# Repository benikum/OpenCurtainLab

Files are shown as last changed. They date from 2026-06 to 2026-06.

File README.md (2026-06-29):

# OpenCurtainLab

**OpenCurtainLab is an open-source shutter tester for analog camera shutters.**

It combines an ESP32, five optical sensor channels, a flash-sync input, an OLED display, and a standalone browser WebUI. The firmware records raw shutter timing locally. The WebUI analyzes that data into exposure time, exposure deviation, shutter spread, curtain travel behavior, flash-sync timing, charts, project history, backups, CSV exports, and standalone camera reports.

OpenCurtainLab is intended for camera repair, calibration work, repeatable shutter testing, and local documentation of analog camera bodies. It does not require a cloud service or proprietary backend.

<p align="center">
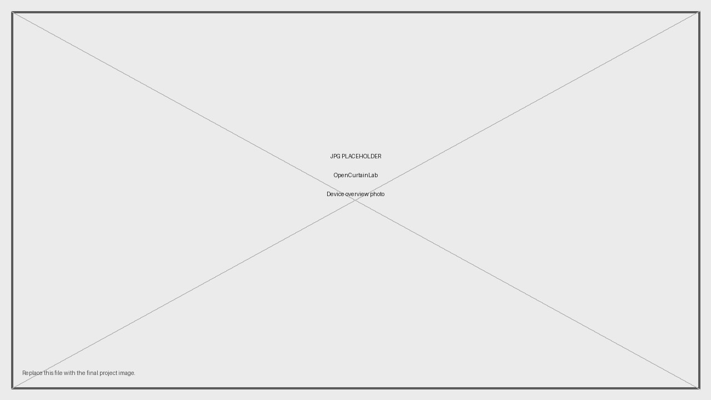
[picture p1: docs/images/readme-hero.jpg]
OpenCurtainLab device
  
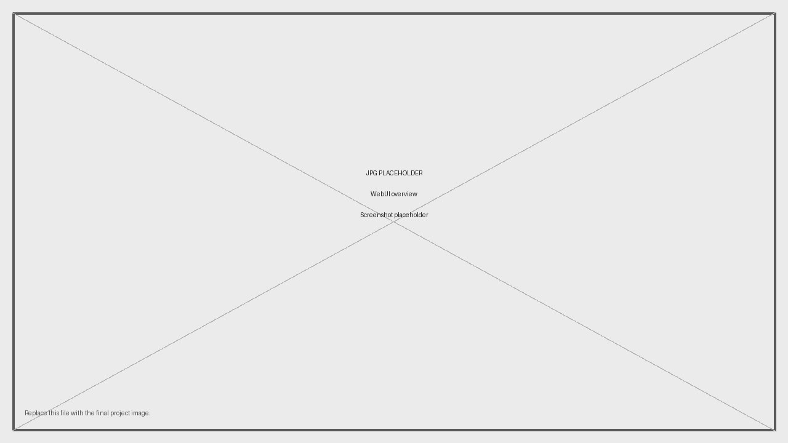
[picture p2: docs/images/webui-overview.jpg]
OpenCurtainLab WebUI
  
</p>

## Features

### Measurement hardware

- Five optical sensor channels for focal-plane shutter timing.
- Measurement modes for horizontal-travel, vertical-travel, and central/leaf shutters.
- Flash-sync input for X-sync timing checks.
- OLED display for setup state, network state, target speed, measurement state, and quick result review.
- Three active-low local buttons for operation without a computer.
- Optional battery-voltage monitoring through a resistor divider.

### Standalone WebUI

- Runs as a normal local HTML file after being downloaded from the device.
- Connects to the ESP32 over the local network.
- Shows measured exposure time, deviation from target speed, shutter spread, and measurement hints.
- Provides timeline, curtain-speed, exposure, and flash-sync visualizations.
- Stores projects and measurement history in browser storage.
- Supports workspace backup import/export, calculated CSV export, and standalone HTML camera reports.

### Local HTTP API

- Local endpoints for status, configuration, diagnostics, WiFi setup, and raw measurement data.
- JSON responses for scripts, tools, or alternative UIs.
- Live sensor diagnostics for wiring, optical alignment, and threshold troubleshooting.

## Repository layout

```text
OpenCurtainLab.ino          Main Arduino sketch and application loop
src/                        Firmware modules, configuration, measurement logic, API, WiFi, OLED
web/                        WebUI source files
web/compiled/               Generated standalone WebUI release file
tools/                      Release and development helper scripts
docs/BUILD_GUIDE.md         Hardware, firmware, and upload guide
docs/API.md                 Firmware HTTP API reference
LICENSE                     Project license
```

## Build the device

The complete hardware and firmware build process is documented here:

**[Open the build guide](docs/BUILD_GUIDE.md)**

The guide covers:

- parts and tools
- ESP32 pinout
- sensor, button, OLED, flash-sync, and battery wiring
- sensor geometry from the current firmware configuration
- Arduino IDE and Arduino CLI setup
- required library versions
- first electrical checks and troubleshooting

<p align="center">
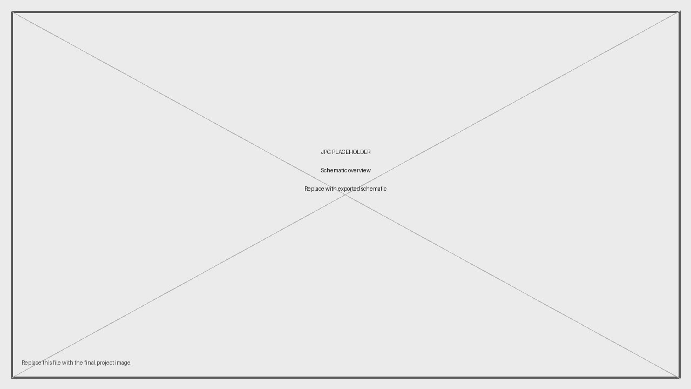
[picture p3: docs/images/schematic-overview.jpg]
OpenCurtainLab electronics overview
  
</p>

## Basic use

### 1. Flash and power the device

Upload the firmware, connect the electronics, and power the ESP32. The OLED shows the current device state.

### 2. Configure WiFi

On first start, the device opens a setup access point named `OpenCurtainLab`. Connect to that access point, open the captive portal, select your WiFi network, enter the password, and save the settings.

### 3. Download the WebUI

After the device is connected to your network, open:

```text
http://opencurtainlab.local
```

The device downloads the compatible compiled WebUI release through the manifest proxy and serves it as `opencurtainlab.html`. Save or open that file in a browser and connect it to the device address shown on the OLED.

### 4. Make a measurement

Place the five-sensor assembly at the camera film gate, point a stable light source through the shutter, select the measurement mode and target speed, and fire the shutter. The firmware records raw timestamps and the WebUI performs the exposure and curtain analysis.

## Local button controls

The three buttons are active-low and wired to GND.

| State | Button | Action |
|---|---|---|
| Ready | Up | Select the next faster target speed. |
| Ready | Down | Select the next slower target speed. |
| Ready | Hold Up | Cycle measurement mode: horizontal, vertical, central. |
| Ready | Select | Open the OLED settings menu. |
| Menu | Up / Down | Move through menu entries. |
| Menu | Select | Change the selected value. |
| Menu | Hold Select | Save menu settings and return to ready mode. |
| Results | Up / Down | Switch result pages or leave the result view. |
| Results | Select | Close result view and return to ready mode. |

The OLED menu gives quick access to sensor sensitivity, target time series, result display behavior, OLED sleep timeout, and network reset.

<p align="center">
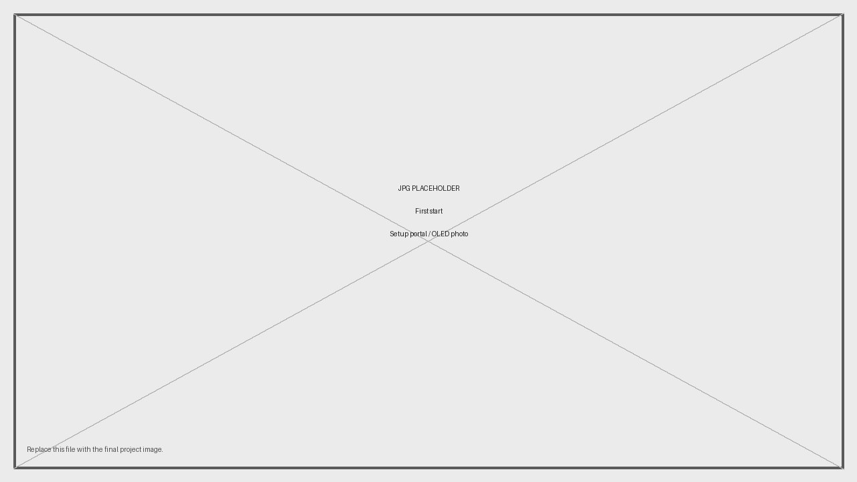
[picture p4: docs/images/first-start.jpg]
OpenCurtainLab first start
  
</p>

## API documentation

The firmware exposes a local HTTP API for status, runtime configuration, WiFi setup, live sensor diagnostics, and measurement data.

**[Open the API documentation](docs/API.md)**

Typical endpoints:

```text
GET  /version
GET  /status
GET  /config
POST /config
GET  /data
GET  /sensors
GET  /wifi/status
GET  /wifi/scan
POST /wifi
```

## AI usage transparency

AI tools were used during development as an assistant for code review, refactoring, documentation drafting, and implementation exploration. The project design, hardware decisions, test results, firmware behavior, API behavior, and published releases remain the responsibility of the maintainer.

## License

OpenCurtainLab is released under the MIT License. See [LICENSE](LICENSE).

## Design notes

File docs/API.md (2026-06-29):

# OpenCurtainLab Firmware API

This document describes the current OpenCurtainLab firmware HTTP API for firmware `0.1.2`. All endpoints are served by the ESP32 on the local network.

The API exposes raw device state and raw measurement data. Exposure analysis, charting, reports, and measurement hints are calculated in the WebUI.

## Security model

OpenCurtainLab is designed for trusted local networks only. The firmware API does not provide user accounts, API tokens, HTTPS, request signing, or per-user permissions.

Do not expose the device to the public internet, do not port-forward it from a router, and do not place it on an untrusted guest network. Anyone who can reach the device on the network can read status data, change runtime settings, access live sensor diagnostics, and use setup endpoints when available.

Recommended use:

- Use a private LAN you control.
- Keep the device behind your router or firewall.
- Avoid public, shared, or guest WiFi networks.
- Power down or disconnect the device when it is not needed in an untrusted environment.

## Base URLs

Station mode:

```text
http://opencurtainlab.local
```

or the station IP address shown on the OLED.

Setup access-point mode:

```text
http://192.168.4.1
```

API responses are JSON unless the endpoint description says otherwise. CORS preflight is supported for the documented API paths.

## Endpoint summary

| Method | Endpoint | Response type | Purpose |
|---|---|---|---|
| `GET` | `/` | HTML | Setup portal in AP mode; WebUI download proxy in station mode. |
| `GET` | `/status` | JSON | Device, network, uptime, measurement counter, battery, and error status. |
| `GET` | `/config` | JSON | Firmware capabilities and current runtime settings. |
| `POST` | `/config` | JSON | Partial runtime settings update. |
| `GET` | `/data` | JSON | Latest raw measurement packet. |
| `GET` | `/sensors` | JSON | Live sensor and flash diagnostics. |
| `GET` | `/version` | JSON | Manifest availability, current firmware, newest project version, and compatible WebUI bugfix version. |
| `GET` | `/wifi/status` | JSON | WiFi provisioning state for the setup portal. |
| `GET` | `/wifi/scan` | JSON | Nearby WiFi networks for the setup portal. |
| `POST` | `/wifi` | JSON | Test and store WiFi credentials while AP mode is active. |

## Current firmware constants exposed by the API

These values come from `src/Config.h` in this release.

| Field | Value |
|---|---:|
| `version` | `0.1.2` |
| `sensorCount` | `5` |
| `sensorDistanceXmm` | `7.62` |
| `sensorDistanceYmm` | `5.08` |
| `maxTargetTime` | `2000` |
| `displayRotation` | `0` |
| `batteryEmptyVoltage` | `7.0` |
| `batteryFullVoltage` | `9.3` |

## Error response format

Most error responses use this compact format:

```json
{
  "ok": false,
  "error": "invalid_json"
}
```

Known error strings:

| Error | Meaning |
|---|---|
| `missing_body` | A `POST` request did not contain a body. |
| `invalid_json` | The submitted JSON could not be parsed. |
| `sensors unavailable` | The sensor manager is not attached. |
| `ssid missing` | WiFi setup request did not include an SSID. |
| `wifi_setup_locked_in_station_mode` | `/wifi` was called while the device was not in setup AP mode. |
| `not found` | Unknown route in station mode. |

## `GET /`

In setup AP mode, root serves the embedded WiFi setup portal.

In station mode, root fetches `web/manifest.json`, selects the newest compatible compiled WebUI entry, downloads the compiled HTML, and returns it to the browser as an attachment:

```http
Content-Disposition: attachment; filename="opencurtainlab.html"
Content-Type: text/html; charset=utf-8
```

The full WebUI is not embedded in firmware. The embedded firmware only contains the setup portal.

## `GET /status`

Returns runtime status.

```bash
curl http://opencurtainlab.local/status
```

Example response:

```json
{
  "device": "OpenCurtainLab",
  "version": "0.1.2",
  "uptime": 1234,
  "measCount": 7,
  "batteryVoltage": 8.62,
  "batteryLow": false,
  "deviceStatus": {
    "error": "none",
    "errorText": "",
    "subsystem": "none"
  },
  "network": {
    "connected": true,
    "apMode": false,
    "ip": "192.168.178.42",
    "apIp": "0.0.0.0",
    "hostname": "opencurtainlab",
    "mdns": "opencurtainlab.local",
    "mdnsStarted": true,
    "rssi": -54,
    "savedSsid": "WorkshopWiFi",
    "currentSsid": "WorkshopWiFi",
    "hint": "none",
    "hintText": ""
  }
}
```

Top-level fields:

| Field | Type | Description |
|---|---|---|
| `device` | string | Device name. |
| `version` | string | Firmware version. |
| `uptime` | integer | Seconds since boot. |
| `measCount` | integer | Number of measurement results produced since boot. |
| `batteryVoltage` | number | Calculated battery voltage, or `0` when battery monitoring is disabled. |
| `batteryLow` | boolean | `true` when battery monitoring is enabled and voltage is at or below `BATTERY_EMPTY_VOLTAGE`. |
| `deviceStatus` | object | Device-level error state. |
| `network` | object | Current WiFi and mDNS state. |

Device error keys:

| Key | Meaning |
|---|---|
| `none` | No device error. |
| `network_access_point_failed` | Setup access point could not be started. |
| `display_init_failed` | OLED initialization failed. Measurement and API can continue. |

Device subsystem keys:

| Key |
|---|
| `none` |
| `sensor` |
| `network` |
| `storage` |
| `display` |

Network hint keys:

| Key | Meaning |
|---|---|
| `none` | No network hint. |
| `no_credentials` | No saved WiFi credentials. |
| `access_point_active` | Setup AP is active. |
| `connection_failed` | Station connection failed or AP fallback is active. |
| `reconnecting` | Device is trying to reconnect. |
| `mdns_failed` | Station WiFi works, but mDNS failed. |

## `GET /config`

Returns firmware capabilities and sanitized runtime settings.

```bash
curl http://opencurtainlab.local/config
```

Example response:

```json
{
  "device": "OpenCurtainLab",
  "version": "0.1.2",
  "ip": "192.168.178.42",
  "mdnsName": "opencurtainlab",
  "sensorDistanceXmm": 7.62,
  "sensorDistanceYmm": 5.08,
  "displayRotation": 0,
  "sensorCount": 5,
  "maxTargetTime": 2000,
  "batteryVoltageEnabled": true,
  "batteryEmptyVoltage": 7.0,
  "batteryFullVoltage": 9.3,
  "sensorReadModel": "absolute_adc_threshold",
  "sensorThresholds": {
    "lowOnRaw": 1100,
    "lowOffRaw": 1250,
    "mediumOnRaw": 2100,
    "mediumOffRaw": 2250,
    "highOnRaw": 3100,
    "highOffRaw": 3250
  },
  "targetSeriesOptions": ["standard", "custom"],
  "targetTimesStandard": [1, 2, 4, 8, 15, 30, 60, 125, 250, 500, 1000, 2000],
  "targetTimesCustom": [1, 2, 5, 10, 25, 50, 100, 250, 500, 1000, 2000],
  "modes": ["vertical", "horizontal", "central"],
  "settings": {
    "defaultMeasurementMode": "horizontal",
    "defaultTargetTime": 500,
    "sensorSensitivity": "medium",
    "resultDisplay": "until_button",
    "targetSeries": "standard",
    "customTargetTimes": [1, 2, 5, 10, 25, 50, 100, 250, 500, 1000, 2000],
    "oledSleepMinutes": 5
  },
  "githubProjectUrl": "https://github.com/benikum/OpenCurtainLab",
  "webManifestUrl": "https://raw.githubusercontent.com/benikum/OpenCurtainLab/refs/heads/main/web/manifest.json",
  "webAppDelivery": "manifest_proxy"
}
```

Capability fields:

| Field | Type | Description |
|---|---|---|
| `sensorDistanceXmm` | number | Physical sensor spacing for horizontal-travel analysis. Current value: `7.62`. |
| `sensorDistanceYmm` | number | Physical sensor spacing for vertical-travel analysis. Current value: `5.08`. |
| `displayRotation` | integer | OLED rotation from firmware config. |
| `sensorCount` | integer | Number of sensor channels. |
| `maxTargetTime` | integer | Maximum accepted target denominator. |
| `batteryVoltageEnabled` | boolean | Whether firmware battery monitoring is enabled. |
| `batteryEmptyVoltage` | number | Voltage used as empty/low reference. |
| `batteryFullVoltage` | number | Voltage used as full reference. |
| `sensorReadModel` | string | Current sensor model. `absolute_adc_threshold` means no calibration baseline is used. |
| `sensorThresholds` | object | Raw ADC hysteresis thresholds for sensitivity presets. |
| `targetSeriesOptions` | string array | Supported target speed series. |
| `targetTimesStandard` | integer array | Built-in standard shutter speed denominators. |
| `targetTimesCustom` | integer array | Current custom shutter speed denominators. |
| `modes` | string array | Supported measurement modes. |

Runtime settings object:

| Field | Type | Values |
|---|---|---|
| `defaultMeasurementMode` | string | `vertical`, `horizontal`, `central` |
| `defaultTargetTime` | integer | Exposure denominator, for example `500` for 1/500 s. |
| `sensorSensitivity` | string | `low`, `medium`, `high` |
| `resultDisplay` | string | `until_button`, `2s`, `5s`, `10s`, `none` |
| `targetSeries` | string | `standard`, `custom` |
| `customTargetTimes` | integer array | Positive exposure denominators. |
| `oledSleepMinutes` | integer | `0`, `1`, `5`, `10`, `30` |

## `POST /config`

Applies a partial runtime-settings update. Omitted fields are left unchanged.

```bash
curl -X POST http://opencurtainlab.local/config \
  -H "Content-Type: application/json" \
  -d '{"sensorSensitivity":"high","defaultTargetTime":250}'
```

Accepted public fields:

| Field | Type | Values |
|---|---|---|
| `defaultMeasurementMode` | string | `vertical`, `horizontal`, `central` |
| `defaultTargetTime` | integer | Exposure denominator. Sanitized to the nearest supported target time. |
| `sensorSensitivity` | string | `low`, `medium`, `high` |
| `resultDisplay` | string | `until_button`, `2s`, `5s`, `10s`, `none` |
| `targetSeries` | string | `standard`, `custom` |
| `customTargetTimes` | integer array | Positive denominators, sorted and de-duplicated by firmware. |
| `oledSleepMinutes` | integer | `0`, `1`, `5`, `10`, `30` |

Successful response:

```json
{
  "ok": true,
  "changed": true,
  "settings": {
    "defaultMeasurementMode": "horizontal",
    "defaultTargetTime": 250,
    "sensorSensitivity": "high",
    "resultDisplay": "until_button",
    "targetSeries": "standard",
    "customTargetTimes": [1, 2, 5, 10, 25, 50, 100, 250, 500, 1000, 2000],
    "oledSleepMinutes": 5
  }
}
```

Notes:

- `maxTargetTime` is a build-time capability and is ignored if posted.
- Invalid enum values fall back to firmware defaults during sanitization.
- Custom target times are sorted, de-duplicated, capped by firmware limits, and filtered against `maxTargetTime`.
- If the request body is syntactically valid JSON but contains no effective change, `changed` is `false`.
- Only the fields documented above are part of the public settings schema for this release.

## `GET /data`

Returns the latest raw measurement packet. Exposure analysis is intentionally performed in the WebUI.

```bash
curl http://opencurtainlab.local/data
```

Before the first measurement:

```json
{
  "measCount": 0,
  "mode": "horizontal",
  "target": 500,
  "sensorDistanceXmm": 7.62,
  "sensorDistanceYmm": 5.08,
  "valid": false
}
```

Example valid measurement:

```json
{
  "measCount": 7,
  "mode": "horizontal",
  "target": 500,
  "sensorDistanceXmm": 7.62,
  "sensorDistanceYmm": 5.08,
  "valid": true,
  "id": "m_123456_7",
  "baseUs": 987654321,
  "sensors": [
    { "id": 0, "activated": true, "raw": 420, "openUs": 987654321, "closeUs": 987656400 },
    { "id": 1, "activated": true, "raw": 390, "openUs": 987654450, "closeUs": 987656530 },
    { "id": 2, "activated": true, "raw": 430, "openUs": 987654600, "closeUs": 987656680 },
    { "id": 3, "activated": true, "raw": 410, "openUs": 987654750, "closeUs": 987656830 },
    { "id": 4, "activated": true, "raw": 405, "openUs": 987654900, "closeUs": 987656980 }
  ],
  "flash": {
    "detected": true,
    "raw": 0,
    "triggerUs": 987654100
  }
}
```

Top-level fields:

| Field | Type | Description |
|---|---|---|
| `measCount` | integer | Measurement counter since boot. |
| `mode` | string | Measurement mode used for the packet. |
| `target` | integer | Target shutter denominator. |
| `sensorDistanceXmm` | number | Horizontal spacing used by the WebUI. |
| `sensorDistanceYmm` | number | Vertical spacing used by the WebUI. |
| `valid` | boolean | Whether the packet contains a measurement result. |
| `id` | string | Measurement id. Present only after a result exists. |
| `baseUs` | integer | Base timestamp in microseconds. Present only after a result exists. |
| `sensors` | array | Raw per-sensor result objects. Present only after a result exists. |
| `flash` | object | Flash-sync result. Present only after a result exists. |

Sensor result fields:

| Field | Type | Description |
|---|---|---|
| `id` | integer | Sensor index, starting at `0`. |
| `activated` | boolean | Whether this sensor was covered during the measurement. |
| `raw` | integer | Last raw ADC value for this sensor. |
| `openUs` | integer | Timestamp when the sensor became active. |
| `closeUs` | integer | Timestamp when the sensor became inactive again. |

Flash result fields:

| Field | Type | Description |
|---|---|---|
| `detected` | boolean | Whether the flash contact was triggered. |
| `raw` | integer | Last raw digital input value. |
| `triggerUs` | integer | Trigger timestamp in microseconds. |

Measurement hints such as timeout, incomplete sensor coverage, and too few sensors are derived by the WebUI from the raw timestamps. The firmware does not emit measurement hint keys in `/data`.

## `GET /sensors`

Returns a live, non-mutating diagnostics snapshot. Diagnostic reads do not create measurement edges.

```bash
curl http://opencurtainlab.local/sensors
```

Example response:

```json
{
  "ok": true,
  "timeUs": 123456789,
  "sensorCount": 5,
  "onThresholdRaw": 2100,
  "offThresholdRaw": 2250,
  "sensors": [
    {
      "id": 0,
      "pin": 36,
      "raw": 4095,
      "onThresholdRaw": 2100,
      "offThresholdRaw": 2250,
      "active": false,
      "trackedActive": false,
      "wasActivated": false,
      "openUs": 0,
      "closeUs": 0
    }
  ],
  "flash": {
    "pin": 14,
    "raw": 1,
    "active": false,
    "trackedActive": false,
    "detected": false,
    "triggerUs": 0
  }
}
```

Sensor diagnostics fields:

| Field | Type | Description |
|---|---|---|
| `timeUs` | integer | ESP32 timestamp in microseconds. |
| `sensorCount` | integer | Number of configured sensors. |
| `onThresholdRaw` | integer | Current activation threshold. |
| `offThresholdRaw` | integer | Current release threshold. |
| `sensors[].pin` | integer | ESP32 GPIO for the sensor. |
| `sensors[].raw` | integer | Current raw ADC value. |
| `sensors[].active` | boolean | Current diagnostic active state from the raw value. |
| `sensors[].trackedActive` | boolean | Measurement engine tracked state. |
| `sensors[].wasActivated` | boolean | Whether the sensor was activated during the current/last measurement window. |
| `flash.pin` | integer | ESP32 GPIO for flash sync. |
| `flash.raw` | integer | Current raw digital value. |
| `flash.active` | boolean | Current diagnostic active state. |

In the WebUI developer console, `oclSensors()` prints the diagnostics as a table when developer helpers are enabled.

## `GET /version`

Returns update information from the remote WebUI manifest. The WebUI uses this to show firmware and WebUI updates separately.

```bash
curl http://opencurtainlab.local/version
```

Example response when the manifest is available:

```json
{
  "manifestAvailable": true,
  "currentFirmware": "0.1.2",
  "projectVersion": "0.1.2",
  "bugfixversion": "0.1.2"
}
```

Example response when the manifest cannot be reached or parsed:

```json
{
  "manifestAvailable": false,
  "currentFirmware": "0.1.2",
  "projectVersion": "",
  "bugfixversion": ""
}
```

Fields:

| Field | Type | Description |
|---|---|---|
| `manifestAvailable` | boolean | `true` when `web/manifest.json` was fetched and parsed. |
| `currentFirmware` | string | Firmware version running on the ESP32. |
| `projectVersion` | string | Newest project version from the manifest. Empty when the manifest is unavailable. |
| `bugfixversion` | string | Highest `entries[].version` whose `match` pattern is compatible with `currentFirmware`. Empty when no compatible manifest entry is available. |

## `GET /wifi/status`

Returns WiFi provisioning state for the setup portal.

```bash
curl http://192.168.4.1/wifi/status
```

Example response:

```json
{
  "ok": true,
  "connected": false,
  "apMode": true,
  "ip": "0.0.0.0",
  "apIp": "192.168.4.1",
  "hostname": "opencurtainlab",
  "mdnsStarted": false,
  "hasSaved": false,
  "savedSsid": "",
  "currentSsid": "",
  "hint": "access_point_active",
  "hintText": "Setup access point is active",
  "lastError": ""
}
```

## `GET /wifi/scan`

Returns nearby WiFi networks for the setup portal.

```bash
curl http://192.168.4.1/wifi/scan
```

Example response:

```json
{
  "ok": true,
  "networks": [
    { "ssid": "WorkshopWiFi", "rssi": -51, "secure": true },
    { "ssid": "Guest", "rssi": -78, "secure": false }
  ]
}
```

## `POST /wifi`

Tests and stores WiFi credentials only while setup AP mode is active.

JSON request:

```bash
curl -X POST http://192.168.4.1/wifi \
  -H "Content-Type: application/json" \
  -d '{"ssid":"WorkshopWiFi","password":"secret-password"}'
```

Form-style fields are also accepted by the firmware.

Successful or failed connection test responses use the same shape as `/wifi/status`. On failed connection, `ok` is `false` and `error` is set:

```json
{
  "ok": false,
  "connected": false,
  "apMode": true,
  "ip": "0.0.0.0",
  "apIp": "192.168.4.1",
  "hostname": "opencurtainlab",
  "mdnsStarted": false,
  "hasSaved": false,
  "savedSsid": "",
  "currentSsid": "",
  "hint": "connection_failed",
  "hintText": "WiFi connection failed",
  "lastError": "connection failed",
  "error": "connection failed"
}
```

When called in station mode:

```json
{
  "ok": false,
  "error": "wifi_setup_locked_in_station_mode"
}
```

## WebUI manifest

The WebUI compatibility database is stored in:

```text
web/manifest.json
```

Current manifest shape:

```json
{
  "schema": "opencurtainlab-web-manifest-v1",
  "projectVersion": "0.1.2",
  "entries": [
    {
      "match": "0.1.x",
      "version": "0.1.2",
      "url": "https://raw.githubusercontent.com/benikum/OpenCurtainLab/refs/heads/main/web/compiled/compiled-v0.1.2.html"
    }
  ]
}
```

Selection rules:

- `projectVersion` is the canonical project version used by `tools/release.py`.
- `match` is the firmware compatibility pattern, for example `0.1.x`.
- `version` is the WebUI release selected for compatible firmware.
- The middle version number is treated as the API version.
- If multiple entries match, the firmware selects the highest patch version.

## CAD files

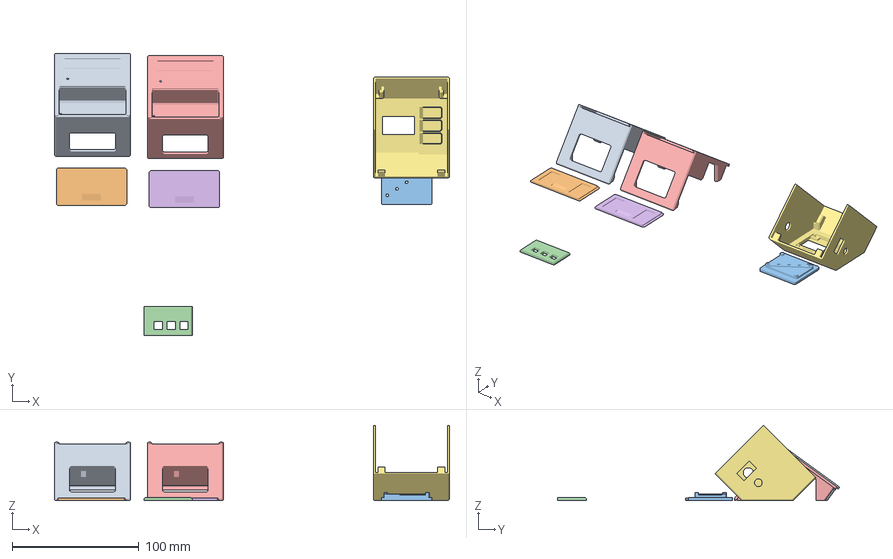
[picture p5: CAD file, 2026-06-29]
3d/OpenCurtainLab - Bambu A1 mini.3mf
311.6 x 222.8 x 59.5 mm
OpenCurtainLab - Case Base.stl x 2
OpenCurtainLab - Battery Door.stl x 2
OpenCurtainLab - Mask.stl
OpenCurtainLab - Button Frame.stl
OpenCurtainLab - Case Outer.stl

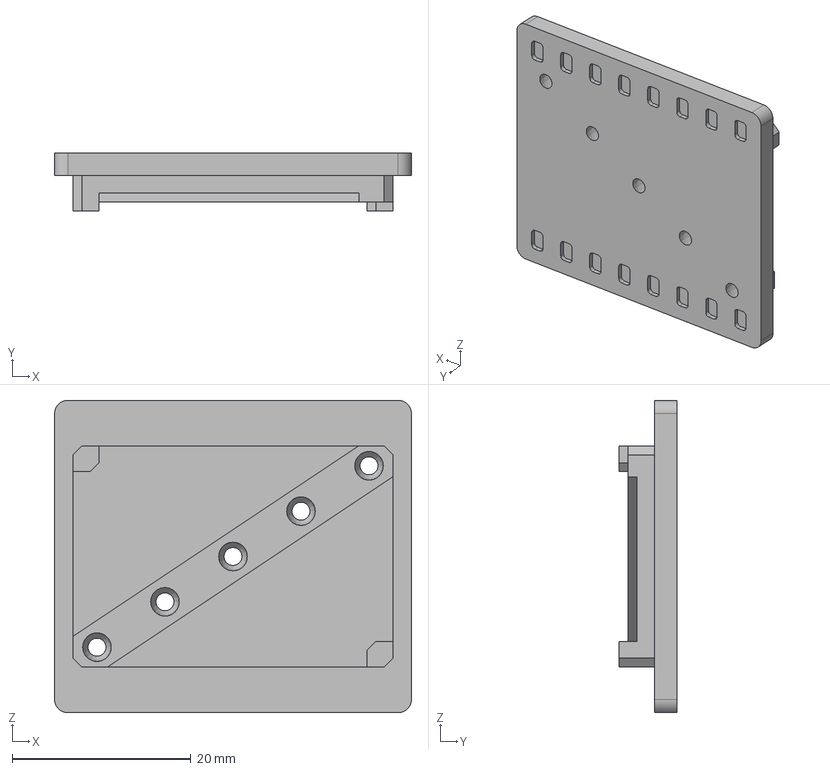
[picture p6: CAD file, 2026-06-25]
3d/step/OpenCurtainLab - Mask.step
40.0 x 6.50 x 35.0 mm

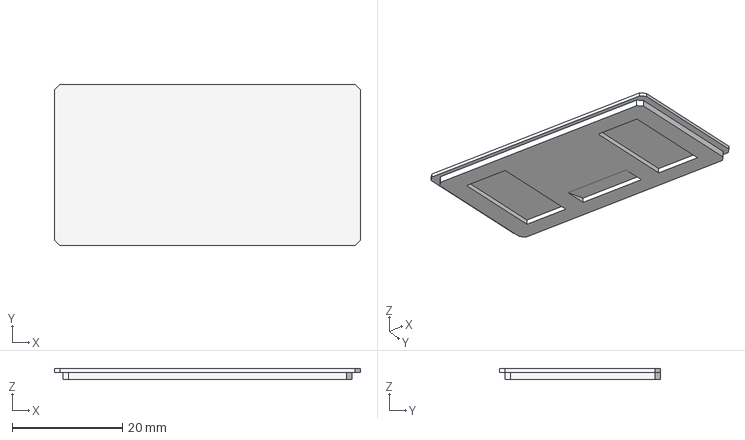
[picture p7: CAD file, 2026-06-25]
3d/step/OpenCurtainLab - Battery Door.step
55.6 x 29.3 x 2.00 mm

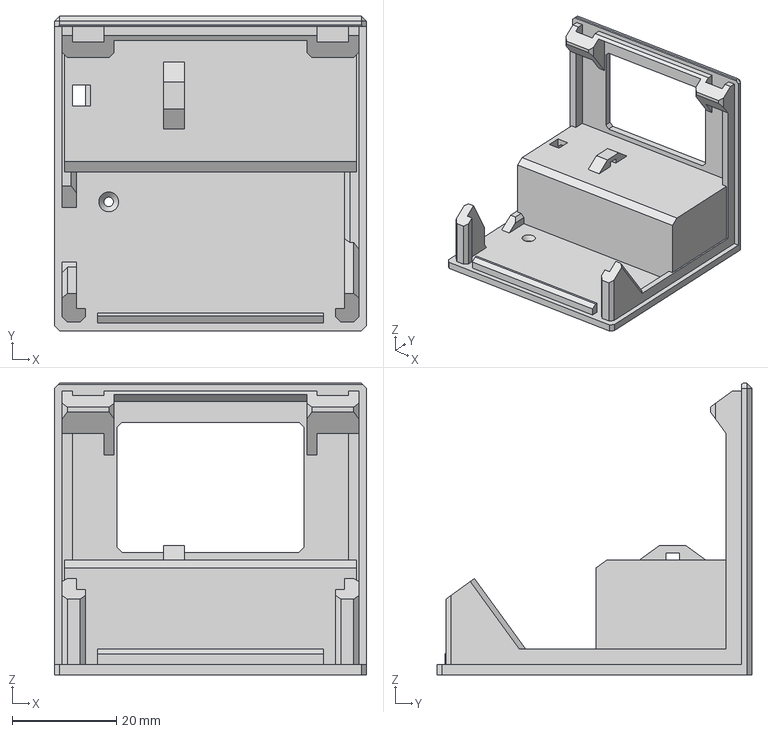
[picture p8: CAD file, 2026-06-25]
3d/step/OpenCurtainLab - Case Base.step
60.0 x 60.5 x 56.0 mm

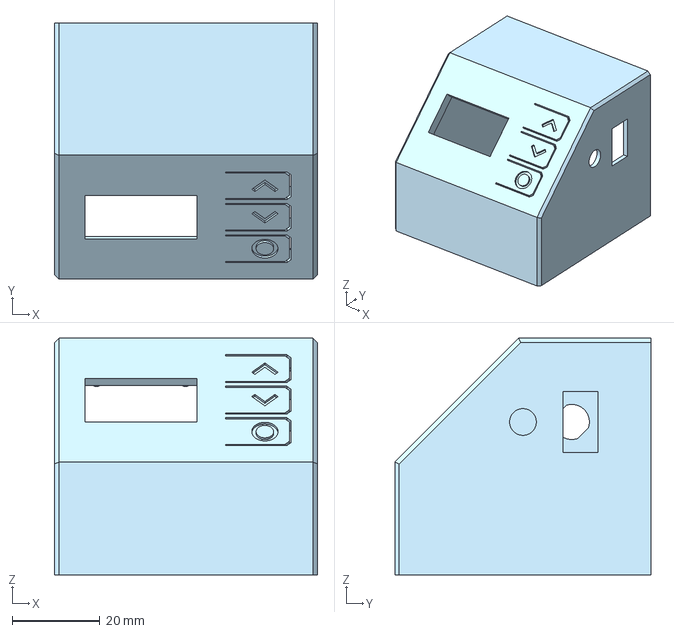
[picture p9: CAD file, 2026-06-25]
3d/step/OpenCurtainLab - Case Outer.step
60.0 x 58.5 x 54.0 mm

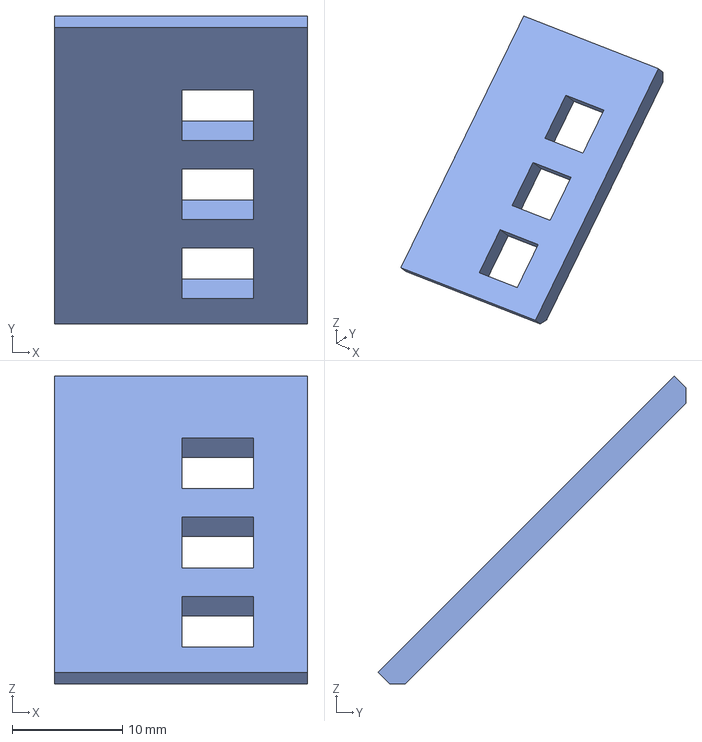
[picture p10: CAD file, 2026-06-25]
3d/step/OpenCurtainLab - Button Frame.step
23.0 x 28.0 x 28.0 mm

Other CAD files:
3d/stl/OpenCurtainLab - Battery Door.stl
3d/stl/OpenCurtainLab - Button Frame.stl
3d/stl/OpenCurtainLab - Case Base.stl
3d/stl/OpenCurtainLab - Case Outer.stl
3d/stl/OpenCurtainLab - Mask.stl

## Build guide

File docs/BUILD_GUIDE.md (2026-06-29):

# OpenCurtainLab Build Guide

This guide describes the current OpenCurtainLab hardware and firmware baseline.

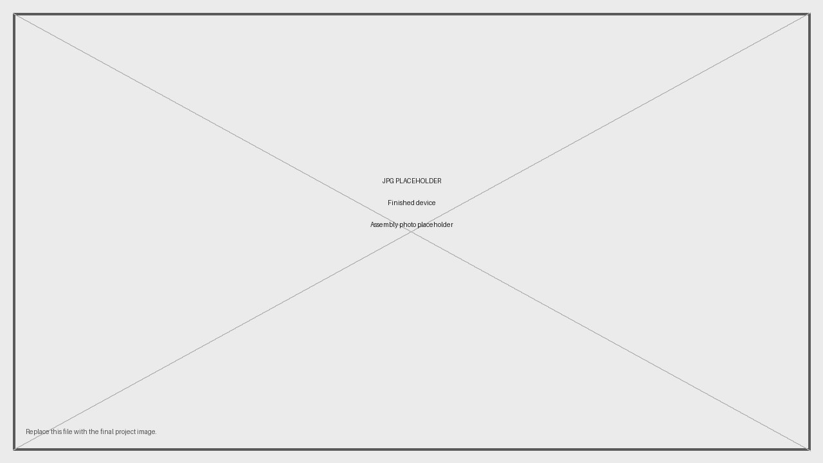
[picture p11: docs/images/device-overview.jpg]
OpenCurtainLab device overview


## 1. Safety and required experience

OpenCurtainLab is a low-voltage ESP32 project, but it still requires careful wiring and testing. Build it only if you are comfortable with soldering, measuring voltage with a multimeter, uploading ESP32 firmware, and checking circuits before applying power.

Do not connect unknown battery voltages directly to an ESP32 development board. Use a suitable regulator or power input for your specific ESP32 board, and verify the voltage before installing the ESP32.

## 2. Parts

Use parts with equivalent electrical ratings and dimensions.

| Qty | Part | Purpose | Notes |
|---:|---|---|---|
| 1 | ESP-WROOM-32 / ESP32 development board | Main controller | Recommended to use a USB Type-C version. |
| 5 | NPN phototransistor, for example PT2046C | Optical shutter sensors | Must have 3mm diameter. |
| 5 | 10 kΩ resistor | Sensor pull-up resistors | One resistor per sensor channel. |
| 1 | SSD1306 OLED display, 128×64 | Local display | Available in different colors. |
| 3 | Momentary push button | Local controls | Active-low buttons wired to GND. |
| 1 | 3.5 mm jack socket or matching sync connector | Flash-sync input | Use 2 or 3 poles version. |
| 1 | Flash-sync cable or hot-shoe adapter | Camera connection | Needed to measure flash timing. |
| 1 | 3.3 V regulator or suitable ESP32 power path | Power supply | Required to use with a 9v battery. Or use USB power. |
| 1 | 330 kΩ resistor | Battery divider high side | Optional battery monitor. |
| 1 | 100 kΩ resistor | Battery divider low side | Optional battery monitor. |
| as needed | Perfboard | Electronics carrier | Boards for sensors, buttons and power distributor. |
| as needed | Headers, wires, connectors | Assembly | Select parts that fit the enclosure and sensor holder. |
| as needed | 3d printed case | Mechanical assembly | Designed to use two filament colors. Use black and some other. |

## 3. Tools

- Soldering iron and solder
- Wire stripper and side cutter
- Multimeter
- Computer with Arduino IDE 2.x or Arduino CLIer
- 3D printer or cnc service

## 4. Firmware baseline

| Setting | Current value |
|---|---|
| Firmware version | `0.1.1` |
| Device name | `OpenCurtainLab` |
| mDNS host | `opencurtainlab.local` |
| Sensor spacing X | `7.62 mm` (`3 × 2.54 mm`) |
| Sensor spacing Y | `5.08 mm` (`2 × 2.54 mm`) |

## 5. ESP32 pinout

The default pinout is defined in `src/Config.h`.

| Function | Firmware symbol | GPIO |
|---|---|---:|
| Sensor 0 | `PIN_SENSOR_0` | 36 |
| Sensor 1 | `PIN_SENSOR_1` | 39 |
| Sensor 2 | `PIN_SENSOR_2` | 34 |
| Sensor 3 | `PIN_SENSOR_3` | 35 |
| Sensor 4 | `PIN_SENSOR_4` | 32 |
| Battery ADC | `PIN_BATTERY_ADC` | 33 |
| Flash sync | `PIN_FLASH_SENSOR` | 14 |
| Up button | `PIN_BTN_UP` | 27 |
| Down button | `PIN_BTN_DOWN` | 26 |
| Select button | `PIN_BTN_SELECT` | 25 |
| OLED SDA | `I2C_SDA` | 21 |
| OLED SCL | `I2C_SCL` | 22 |

GPIO36, GPIO39, GPIO34, and GPIO35 are input-only pins on common ESP32 modules. Do not use ADC2 because of WiFi errors.

## 6. Sensor board

The current geometry is based on perfboard spacing:

```cpp
static constexpr float SENSOR_DISTANCE_X_MM = 3*2.54f; // 7.62 mm
static constexpr float SENSOR_DISTANCE_Y_MM = 2*2.54f; // 5.08 mm
```

Use that geometry when placing neighboring sensors. If you change the physical layout, update `SENSOR_DISTANCE_X_MM` and `SENSOR_DISTANCE_Y_MM` in `src/Config.h` before building firmware and release files.

Recommended circuit per sensor:

```text
3.3 V ---- 10 kΩ ----+---- ESP32 ADC pin
                     |
              phototransistor
                     |
GND -----------------+
```

Current threshold presets:

| Sensitivity | Active when raw is at or below | Released when raw is at or above |
|---|---:|---:|
| Low | 1100 | 1250 |
| Medium | 2100 | 2250 |
| High | 3100 | 3250 |

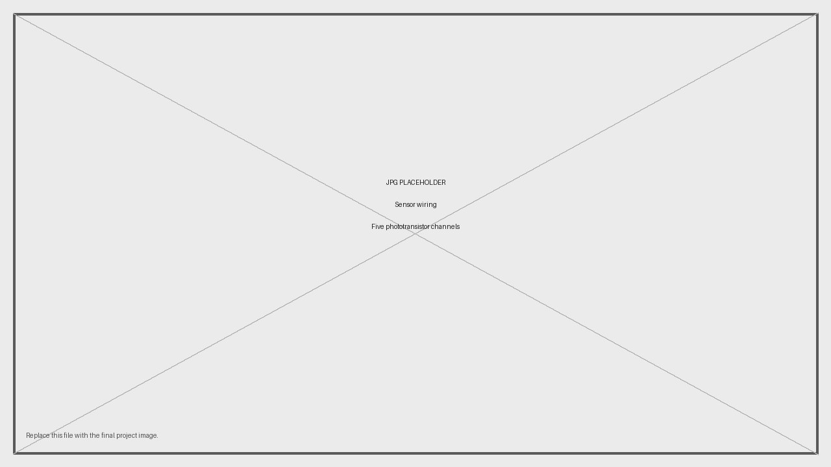
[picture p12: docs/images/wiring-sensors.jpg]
Sensor wiring


## 7. Flash-sync input

The flash-sync input is active-low and uses the ESP32 internal pull-up.

```text
3.5 mm jack tip    ---- GPIO14 / PIN_FLASH_SENSOR
3.5 mm jack sleeve ---- GND
```

## 8. OLED display

Connect the SSD1306 OLED over I2C:

```text
OLED VCC  -> 3.3 V
OLED GND  -> GND
OLED SDA  -> GPIO21 / I2C_SDA
OLED SCL  -> GPIO22 / I2C_SCL
```

Default display configuration:

```cpp
#define OLED_ADDRESS     0x3C
#define SCREEN_WIDTH     128
#define SCREEN_HEIGHT    64
#define DISPLAY_ROTATION 0
```

## 9. Buttons

All buttons are active-low. Wire each button between the configured GPIO and GND.

```text
GPIO27 -- Up button ----- GND
GPIO26 -- Down button --- GND
GPIO25 -- Select button - GND
```

## 10. Battery monitor

Battery monitoring is enabled by default:

```cpp
static constexpr bool BATTERY_MONITOR_ENABLED = true;
```

The current divider uses nominal 330 kΩ / 100 kΩ values:

```text
Battery + ---- 330 kΩ ----+---- GPIO33 / PIN_BATTERY_ADC
                          |
                        100 kΩ
                          |
GND ----------------------+
```

The current firmware values are:

```cpp
#define BATTERY_DIVIDER_HIGH_OHMS  330000.0f
#define BATTERY_DIVIDER_LOW_OHMS   100000.0f
#define BATTERY_EMPTY_VOLTAGE      7.0f
#define BATTERY_FULL_VOLTAGE       9.3f
```

For better accuracy, measure the installed resistors and enter the actual values in `src/Config.h`.

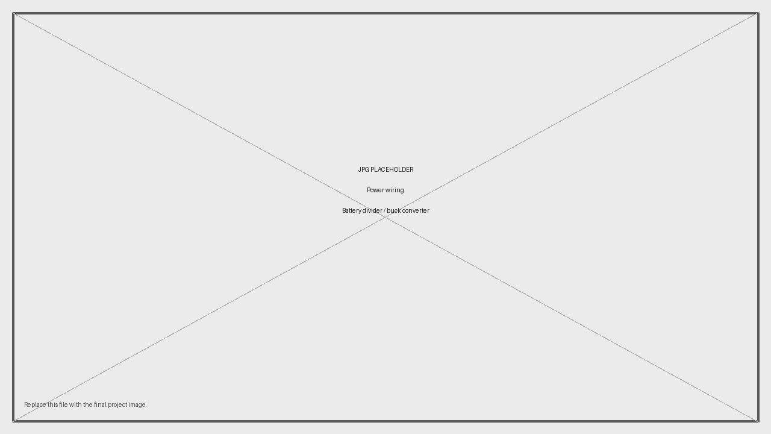
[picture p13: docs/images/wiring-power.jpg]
Power wiring


## 11. Board and enclosure layout

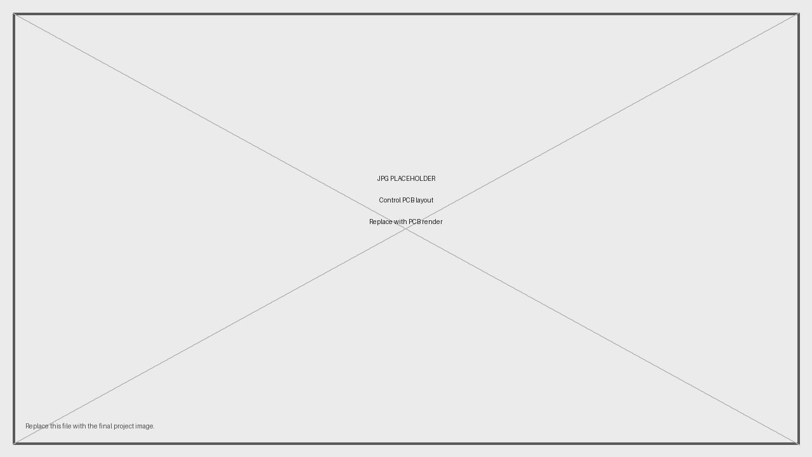
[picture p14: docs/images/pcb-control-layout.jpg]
Control board layout


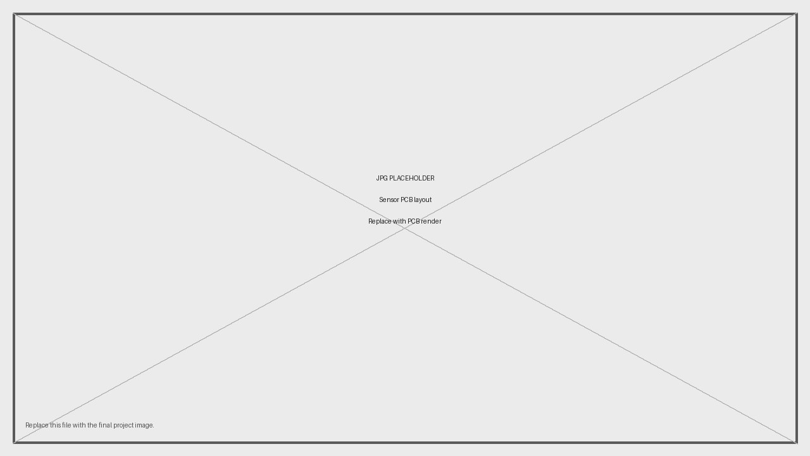
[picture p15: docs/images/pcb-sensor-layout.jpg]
Sensor board layout


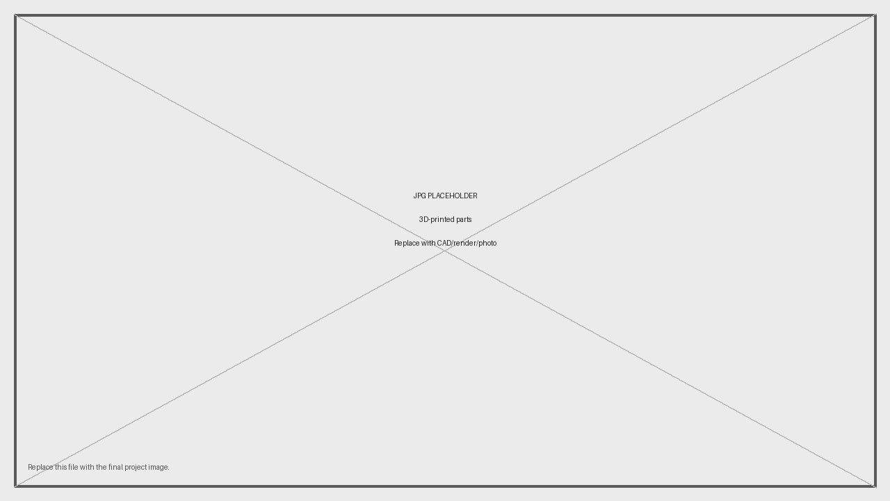
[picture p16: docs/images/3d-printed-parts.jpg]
Mechanical parts


## 12. Assembly

### Step 1: Prepare the electronics carrier

1. Cut the perfboard or prepare the PCBs.
2. Mark connector orientation and signal names.
3. Inspect copper tracks, pads, and solder bridges.
4. Keep the ESP32 uninstalled until the power rails have been checked.

### Step 2: Assemble the sensor channels

1. Install the five phototransistors.
2. Install one 10 kΩ pull-up resistor per sensor channel.
3. Connect each sensor node to its configured ESP32 ADC pin.
4. Connect all sensor grounds to common GND.
5. Check resistance between 3.3 V and GND before applying power.

### Step 3: Assemble display, buttons, flash sync, and battery divider

1. Wire OLED VCC, GND, SDA, and SCL.
2. Wire Up, Down, and Select buttons to GPIO27, GPIO26, GPIO25, and GND.
3. Wire the flash-sync jack to GPIO14 and GND.
4. Install the battery divider if battery monitoring is used.

### Step 4: Verify power

1. Power the regulator or board input without the ESP32 installed, if possible.
2. Confirm the 3.3 V rail with a multimeter.
3. Confirm common ground between the main board and sensor board.
4. Check that no signal pin is shorted to 3.3 V or GND.

### Step 5: Install and power the ESP32

1. Install or plug in the ESP32 board.
2. Power from USB first.
3. Confirm that the OLED initializes.
4. Confirm that the setup AP appears on first boot if no WiFi credentials are saved.

### Step 6: Mechanical installation

1. Install the sensor board in the sensor holder.
2. Install the main electronics in the enclosure.
3. Route sensor and sync cables with strain relief.
4. Keep all sharp solder joints and wire ends away from camera surfaces.
5. Close the enclosure only after diagnostics pass.

## 13. Firmware setup

### 13.1 Recommended toolchain and library versions

These versions are pinned for reproducible builds of the current source tree.

| Component | Version | Why it is needed |
|---|---:|---|
| ESP32 Arduino core by Espressif Systems | `3.3.10` | Provides ESP32 board support, WiFi, WebServer, Preferences, mDNS, ADC, GPIO, timing, HTTPClient, and WiFiClientSecure. |
| ArduinoJson | `7.4.3` | JSON serialization and parsing for firmware API responses, settings updates, WiFi setup, and WebUI manifest handling. |
| Adafruit GFX Library | `1.12.6` | Graphics base library used by the OLED driver. |
| Adafruit SSD1306 | `2.5.17` | SSD1306 OLED driver. |
| Adafruit BusIO | `1.17.4` | Adafruit display stack dependency for I2C/SPI bus helpers. |

`Wire`, `WiFi`, `WebServer`, `Preferences`, `DNSServer`, `ESPmDNS`, `HTTPClient`, and `WiFiClientSecure` are provided by the ESP32 Arduino core and do not need separate Library Manager installs.

Last checked for this guide: 2026-06-29.

### 13.2 Arduino IDE setup

1. Install Arduino IDE 2.x.
2. Add the Espressif ESP32 Boards Manager URL in Arduino IDE preferences:

```text
https://espressif.github.io/arduino-esp32/package_esp32_index.json
```

3. Open **Tools → Board → Boards Manager**.
4. Search for `esp32`.
5. Install **esp32 by Espressif Systems**, version `3.3.10`.
6. Open **Tools → Manage Libraries**.
7. Install the exact library versions listed above.
8. Open `OpenCurtainLab.ino`.
9. Select your ESP32 board and port.
10. Compile and upload.

## 14. Runtime configuration

Open `src/Config.h` when adapting the build to different hardware.

Common values to adjust:

| Setting | Meaning |
|---|---|
| `BATTERY_MONITOR_ENABLED` | Set to `false` when the battery divider is not installed. |
| `BATTERY_DIVIDER_HIGH_OHMS` / `BATTERY_DIVIDER_LOW_OHMS` | Installed battery-divider resistor values. |
| `BATTERY_EMPTY_VOLTAGE` / `BATTERY_FULL_VOLTAGE` | Voltage range used for battery percentage. |
| `SENSOR_DISTANCE_X_MM` / `SENSOR_DISTANCE_Y_MM` | Physical spacing between neighboring sensors. |
| `SENSOR_ON_THRESHOLD_*` / `SENSOR_OFF_THRESHOLD_*` | Raw ADC hysteresis thresholds for light detection. |

After changing firmware constants or WebUI files, run the release helper before publishing generated files:

```bash
python3 tools/release.py
```

## 15. First checks

1. Open the serial monitor after upload.
2. Confirm that the OLED shows a valid startup state.
3. Connect to the `OpenCurtainLab` setup AP on first boot.
4. Configure WiFi.
5. Open `http://opencurtainlab.local` or the IP shown on the OLED.
6. Download the WebUI.
7. Open `/sensors` and check all raw sensor values in darkness and under light.
8. Trigger the flash-sync input manually and confirm that the flash diagnostic changes.
9. Make a test measurement without a camera before inserting the sensor holder into a camera body.

## 16. Troubleshooting

| Symptom | Likely cause | Check |
|---|---|---|
| Setup portal does not appear | Device is not in AP mode or power is unstable | OLED state, serial log, `OpenCurtainLab` WiFi network. |
| `opencurtainlab.local` does not resolve | mDNS unavailable on client | Use the IP address shown on the OLED. |
| OLED stays blank | Wrong I2C address, wiring issue, display fault | SDA/SCL, VCC, GND, `OLED_ADDRESS`. |
| Sensor is always active | Light leak, inverted wiring, threshold too high | `/sensors` raw value, phototransistor orientation. |
| Sensor never activates | Missing pull-up, phototransistor orientation, weak light, threshold too low | ADC voltage and `/sensors` raw value. |
| One sensor behaves differently | Solder joint, wrong resistor, damaged sensor, mechanical shadow | Compare raw values across all five channels. |
| Flash is always active | Jack shorted to GND | GPIO14 against GND. |
| Flash never triggers | Wrong cable/contact, no common ground, wrong jack wiring | Flash raw value in `/sensors`. |
| Battery shows `0 V` | Battery monitor disabled or divider missing | `BATTERY_MONITOR_ENABLED` and GPIO33 wiring. |
| Battery value is inaccurate | Nominal divider values differ from installed values | Measure resistors and update `Config.h`. |
| WebUI download fails | Manifest URL unavailable or WiFi problem | `/status`, `/version`, network access, manifest URL. |

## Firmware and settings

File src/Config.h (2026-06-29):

/*
 * Defines firmware identity, hardware pins, sensor geometry, timing constants, WiFi behavior, and factory defaults.
 */

#pragma once
#include <Arduino.h>

// Project / URLs
#define DEVICE_NAME                 "OpenCurtainLab"
#define FIRMWARE_VERSION            "0.1.1"
#define MDNS_NAME                   "opencurtainlab"
#define GITHUB_PROJECT_URL          "https://github.com/benikum/OpenCurtainLab"
#define WEB_MANIFEST_URL            "https://raw.githubusercontent.com/benikum/OpenCurtainLab/refs/heads/main/web/manifest.json"
#define WEB_APP_DOWNLOAD_FILENAME   "opencurtainlab.html"

// Remote manifest/download proxy
#define WEB_MANIFEST_TIMEOUT_MS        8000UL
#define WEB_APP_PROXY_TIMEOUT_MS       12000UL
#define WEB_APP_STREAM_BUFFER_SIZE     1024

// WiFi / Setup AP
#define SETUP_AP_SSID                    "OpenCurtainLab"
#define SETUP_AP_PASSWORD                ""
#define WIFI_CONNECT_TIMEOUT_MS          12000UL
#define WIFI_RECONNECT_INTERVAL_MS       30000UL
#define WIFI_FALLBACK_TO_AP_TIMEOUT_MS   90000UL
#define MDNS_RETRY_INTERVAL_MS           10000UL

// Hardware Pins
#define PIN_SENSOR_0      36
#define PIN_SENSOR_1      39
#define PIN_SENSOR_2      34
#define PIN_SENSOR_3      35
#define PIN_SENSOR_4      32
#define PIN_BATTERY_ADC   33
#define PIN_FLASH_SENSOR  14

// Buttons
#define PIN_BTN_UP        27
#define PIN_BTN_DOWN      26
#define PIN_BTN_SELECT    25
#define DEBOUNCE_MS       50UL
#define MODE_HOLD_MS      1000UL

// Battery voltage monitor
static constexpr bool BATTERY_MONITOR_ENABLED = true;
#define BATTERY_DIVIDER_HIGH_OHMS  330000.0f
#define BATTERY_DIVIDER_LOW_OHMS   100000.0f
#define BATTERY_EMPTY_VOLTAGE      7.0f
#define BATTERY_FULL_VOLTAGE       9.3f
#define BATTERY_ADC_SAMPLES        8
#define BATTERY_UPDATE_INTERVAL_MS 1000UL

// Display / I2C
#define I2C_SDA              21
#define I2C_SCL              22
#define OLED_ADDRESS         0x3C
#define SCREEN_WIDTH         128
#define SCREEN_HEIGHT        64
#define DISPLAY_ROTATION     0

// Sensor Geometry (perfboard spacing)
static constexpr int SENSOR_COUNT = 5;
static constexpr float SENSOR_DISTANCE_X_MM = 3*2.54f;
static constexpr float SENSOR_DISTANCE_Y_MM = 2*2.54f;

// Runtime sensitivity presets use absolute ADC hysteresis thresholds
#define SENSOR_ON_THRESHOLD_LOW      1100
#define SENSOR_OFF_THRESHOLD_LOW     1250
#define SENSOR_ON_THRESHOLD_MEDIUM   2100
#define SENSOR_OFF_THRESHOLD_MEDIUM  2250
#define SENSOR_ON_THRESHOLD_HIGH     3100
#define SENSOR_OFF_THRESHOLD_HIGH    3250

// Measurement Timing
#define MEASUREMENT_TIMEOUT_MS       5000UL
#define MEASUREMENT_SETTLE_MS        15UL
#define MEASUREMENT_LATE_SENSOR_SETTLE_MS 120UL
#define FLASH_TO_SENSOR_TIMEOUT_MS   250UL

// Factory defaults for runtime settings
#define DEFAULT_MEASUREMENT_MODE    "horizontal"
#define DEFAULT_TARGET_TIME         500
#define DEVICE_MAX_TARGET_TIME      2000
#define DEFAULT_SENSOR_SENSITIVITY  "medium"
#define DEFAULT_RESULT_DISPLAY      "until_button"
#define DEFAULT_OLED_SLEEP_MINUTES  5

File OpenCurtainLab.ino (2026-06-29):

/*
 * Coordinates the OpenCurtainLab application state, buttons, display, sensors, measurement engine, settings, and web API.
 */

#include <Arduino.h>
#include <ArduinoJson.h>
#include "src/Config.h"
#include "src/MeasurementTypes.h"
#include "src/TargetTimes.h"
#include "src/RuntimeSettings.h"
#include "src/SensorManager.h"
#include "src/MeasurementEngine.h"
#include "src/DisplayManager.h"
#include "src/ButtonManager.h"
#include "src/BatteryMonitor.h"
#include "src/WebServerManager.h"

SensorManager     sensorManager;
MeasurementEngine engine(sensorManager);
DisplayManager    displayManager;
ButtonManager     buttonManager;
BatteryMonitor    batteryMonitor;
WebServerManager  webServer;

enum class AppState : uint8_t {
  READY,
  MEASURING,
  RESULTS,
  MENU
};

AppState appState = AppState::READY;

int targetIndex = 0;
int targetFraction = DEFAULT_TARGET_TIME;
TargetSeries targetSeries = TargetSeries::Standard;
MeasurementMode measureMode = MeasurementMode::HORIZONTAL;
String resultDisplayMode = DEFAULT_RESULT_DISPLAY;
int oledSleepMinutes = DEFAULT_OLED_SLEEP_MINUTES;

bool displayAvailable = false;
bool oledSleeping = false;
bool suppressButtonsUntilReleased = false;
unsigned long lastUserActivity = 0;

bool displayDirty = true;
unsigned long lastDisplayUpdate = 0;
const unsigned long DISPLAY_REFRESH_MS = 100;

const unsigned long OLED_NOTICE_MS = 2800UL;
const uint8_t OLED_NOTICE_QUEUE_SIZE = 4;
struct OledNotice {
  char title[18];
  char message[72];
};
OledNotice activeOledNotice = {{0}, {0}};
OledNotice oledNoticeQueue[OLED_NOTICE_QUEUE_SIZE];
uint8_t oledNoticeHead = 0;
uint8_t oledNoticeCount = 0;
unsigned long oledNoticeStartedMs = 0;
unsigned long oledNoticeDurationMs = 0;
DeviceError lastOledDeviceError = DeviceError::None;
NetworkHint lastOledNetworkHint = NetworkHint::None;
bool oledFlashContactClosed = false;

uint8_t resultPage = 1;
unsigned long resultStartedMs = 0;
unsigned long resultDurationMs = 0;
unsigned long lastReadyArmAttempt = 0;
const unsigned long READY_ARM_RETRY_MS = 250;
MeasurementResult displayedResult;
DisplayResultSummary displayedSummary;
MeasurementMode displayedMode = MeasurementMode::HORIZONTAL;

uint8_t menuIndex = 0;
const uint8_t MENU_COUNT = 5;
RuntimeSettings menuDraft;
bool menuDirty = false;

void handleButtons();
void handleEngineState();
void runCriticalMeasurementLoop();
void refreshDisplay();
void setAppState(AppState next);
bool hasBlockingDeviceError();
void cycleMeasureMode();
void applyRuntimeSettings(bool applySelection, bool useSavedTargetTime);
void applyUiSettings(const RuntimeSettings& cfg);
void applyTargetSettings(const RuntimeSettings& cfg, bool useSavedTargetTime);
void applySensorSettings(const RuntimeSettings& cfg);
void setDeviceError(DeviceError error, DeviceSubsystem subsystem);
void clearDeviceError(DeviceSubsystem subsystem = DeviceSubsystem::None);
bool hasDeviceError();
DeviceError currentDeviceError();
NetworkHint currentNetworkHint();
void monitorOledDiagnostics();
void monitorFlashContactIndicator();
bool isFlashContactClosed();
void enqueueOledNotice(const char* title, const char* message);
void startNextOledNotice();
bool isOledNoticeActive();
void updateOledNoticeTimer();
void handleWifiEvents();
void noteUserActivity();
void updateOledSleep();
bool areButtonsReleased();
bool enterReady();
bool startMeasurementFromCurrentSettings(bool noteActivity = true);
void maintainReadyCapture();
void closeResultsAndReady();
void openMenu();
void closeMenuAndReady();
void saveMenuDraftAndReady();
void handleMenuButtons(const ButtonEvents& ev);
void applyMenuSetting(uint8_t idx);
void buildMenuValues(const char* values[MENU_COUNT]);
void updateResultsTimeout();
void processNewResult();
String menuDraftJson();

// Initializes hardware, networking, settings, and the first ready capture.
void setup() {
  Serial.begin(115200);
  delay(300);
  Serial.println(F("\n=============================="));
  Serial.println(F("     OpenCurtainLab ESP32"));
  Serial.println(F("=============================="));


  const bool displayOk = displayManager.begin();
  displayAvailable = displayOk;
  if (!displayOk) {
    webServer.setDeviceError(DeviceError::DisplayInitFailed, DeviceSubsystem::Display);
  }
  buttonManager.begin();
  sensorManager.begin();
  batteryMonitor.begin();
  engine.setMode(measureMode);
  webServer.attachSensorManager(sensorManager);
  webServer.attachBatteryMonitor(batteryMonitor);

  webServer.begin(WIFI_CONNECT_TIMEOUT_MS);
  applyRuntimeSettings(true, true);
  webServer.consumeWifiEvent();

  Serial.printf("[Main] Target time: 1/%d s\n", targetFraction);
  Serial.printf("[Main] Mode: %s\n", measurementModeKey(measureMode));
  lastUserActivity = millis();
  enterReady();
  monitorOledDiagnostics();

  // Draw the first steady screen immediately so the splash is not left visible
  // until the next scheduler tick.
  refreshDisplay();
  displayDirty = false;
  lastDisplayUpdate = millis();
}

// Runs the main cooperative scheduler outside the critical capture loop.
void loop() {
  // Measurement time is handled first so the high-rate polling path cannot be delayed by UI or web work.
  if (appState == AppState::MEASURING) {
    runCriticalMeasurementLoop();
    handleEngineState();
    updateOledSleep();
    return;
  }

  // Settings can change from the WebUI; reapply them centrally.
  if (webServer.consumeSettingsChanged()) {
    const bool applySelection = webServer.consumeSettingsSelectionChanged();
    const bool useSavedTargetTime = webServer.consumeSettingsTargetTimeSelectionChanged();
    applyRuntimeSettings(applySelection, useSavedTargetTime);
    noteUserActivity();

    if (appState == AppState::MENU) {
      menuDraft = webServer.getSettings();
      menuDirty = false;
      displayDirty = true;
    } else {
      enterReady();
    }
  }

  // Normal cooperative work is only done outside the critical measuring window.
  handleButtons();
  maintainReadyCapture();

  if (appState == AppState::RESULTS) engine.update();

  // READY means the engine should stay armed unless a capture-blocking device error is active.
  if (!hasBlockingDeviceError() && appState == AppState::READY) {
    engine.update();
    if (engine.isCapturing()) {
      setAppState(AppState::MEASURING);
      runCriticalMeasurementLoop();
    }
  }

  handleEngineState();
  updateResultsTimeout();

  if (displayDirty && (millis() - lastDisplayUpdate) >= DISPLAY_REFRESH_MS) {
    refreshDisplay();
    displayDirty = false;
    lastDisplayUpdate = millis();
  }

  if (appState != AppState::MEASURING) {
    batteryMonitor.update();
    webServer.update();
    handleWifiEvents();
    monitorOledDiagnostics();
    monitorFlashContactIndicator();
  }
  updateOledNoticeTimer();
  updateOledSleep();
}

// Keeps the sensor engine polling as fast as possible while a shutter event is being captured.
void runCriticalMeasurementLoop() {
  // Critical measurement loop: block non-measurement tasks until the shutter
  // event is finished. This maximizes sensor polling rate during the few
  // milliseconds that matter. A periodic yield keeps the watchdog safe if a
  // timeout measurement runs unusually long.
  uint16_t watchdogYieldCounter = 0;
  while (engine.isCapturing()) {
    engine.update();
    if (++watchdogYieldCounter == 0) delay(0);
  }
}

// Routes button events according to the current app state.
void handleButtons() {
  ButtonEvents ev = buttonManager.poll();

  // After the OLED wakes up, ignore held buttons until the user releases them to avoid accidental actions.
  if (suppressButtonsUntilReleased) {
    if (areButtonsReleased()) suppressButtonsUntilReleased = false;
    return;
  }

  if (ev.anyPressed()) {
    if (oledSleeping) {
      noteUserActivity();
      suppressButtonsUntilReleased = true;
      return;
    }
    noteUserActivity();
  }

  if (appState == AppState::MENU) {
    handleMenuButtons(ev);
    return;
  }

  // Result navigation is modal: buttons either change result page or return to READY.
  if (appState == AppState::RESULTS) {
    if (ev.selectPressed) {
      closeResultsAndReady();
      return;
    }

    if (ev.upPressed) {
      if (resultPage == 1) resultPage = 2;
      else closeResultsAndReady();
      displayDirty = true;
      return;
    }

    if (ev.downPressed) {
      if (resultPage == 2) resultPage = 1;
      else closeResultsAndReady();
      displayDirty = true;
      return;
    }
    return;
  }

  if (appState != AppState::READY) return;

  if (ev.selectPressed) {
    openMenu();
    return;
  }

  if (ev.upLongPressed) {
    cycleMeasureMode();
    return;
  }

  if (ev.upPressed && targetIndex < maxTargetIndex(targetSeries)) {
    targetIndex++;
    targetFraction = targetTimeAt(targetIndex, targetSeries);
    Serial.printf("[Main] Target time: 1/%d s\n", targetFraction);
    enterReady();
  }

  if (ev.downPressed && targetIndex > 0) {
    targetIndex--;
    targetFraction = targetTimeAt(targetIndex, targetSeries);
    Serial.printf("[Main] Target time: 1/%d s\n", targetFraction);
    enterReady();
  }
}

// Stops capture and opens the local OLED settings menu.
void openMenu() {
  Serial.println(F("[Main] Menu opened."));
  engine.cancel();
  setAppState(AppState::MENU);
  menuDraft = webServer.getSettings();
  menuDirty = false;
  menuIndex = 0;
  resultStartedMs = 0;
  resultDurationMs = 0;
  displayDirty = true;
}

// Closes the menu without further changes and returns to ready mode.
void closeMenuAndReady() {
  menuDirty = false;
  enterReady();
}

// Persists pending menu changes, applies them, and returns to ready mode.
void saveMenuDraftAndReady() {
  if (menuDirty) {
    webServer.applySettingsJson(menuDraftJson());
    webServer.consumeSettingsChanged();
    const bool applySelection = webServer.consumeSettingsSelectionChanged();
    const bool useSavedTargetTime = webServer.consumeSettingsTargetTimeSelectionChanged();
    applyRuntimeSettings(applySelection, useSavedTargetTime);
  }
  closeMenuAndReady();
}

// Handles navigation and editing while the settings menu is open.
void handleMenuButtons(const ButtonEvents& ev) {
  if (ev.selectLongPressed) {
    saveMenuDraftAndReady();
    return;
  }
  if (ev.upPressed && menuIndex > 0) {
    menuIndex--;
    displayDirty = true;
    return;
  }
  if (ev.downPressed && menuIndex + 1 < MENU_COUNT) {
    menuIndex++;
    displayDirty = true;
    return;
  }
  if (ev.selectPressed) {
    applyMenuSetting(menuIndex);
    displayDirty = true;
  }
}

// Cycles the editable setting at the selected menu row.
void applyMenuSetting(uint8_t idx) {
  // Each menu row cycles through a small fixed set of values to keep local control simple.
  switch (idx) {
    case 0:
      if (menuDraft.sensorSensitivity == "medium") menuDraft.sensorSensitivity = "high";
      else if (menuDraft.sensorSensitivity == "high") menuDraft.sensorSensitivity = "low";
      else menuDraft.sensorSensitivity = "medium";
      menuDirty = true;
      break;

    case 1:
      menuDraft.targetSeries = nextTargetSeries(menuDraft.targetSeries);
      menuDirty = true;
      break;

    case 2:
      menuDraft.resultDisplayMode = nextResultDisplayMode(menuDraft.resultDisplayMode);
      menuDirty = true;
      break;

    case 3:
      if (menuDraft.oledSleepMinutes == 0) menuDraft.oledSleepMinutes = 1;
      else if (menuDraft.oledSleepMinutes == 1) menuDraft.oledSleepMinutes = 5;
      else if (menuDraft.oledSleepMinutes == 5) menuDraft.oledSleepMinutes = 10;
      else if (menuDraft.oledSleepMinutes == 10) menuDraft.oledSleepMinutes = 30;
      else menuDraft.oledSleepMinutes = 0;
      menuDirty = true;
      break;

    case 4:
      // Save pending menu changes before clearing WiFi so no local setting edits are lost.
      if (menuDirty) {
        webServer.applySettingsJson(menuDraftJson());
        webServer.consumeSettingsChanged();
        const bool applySelection = webServer.consumeSettingsSelectionChanged();
        const bool useSavedTargetTime = webServer.consumeSettingsTargetTimeSelectionChanged();
        applyRuntimeSettings(applySelection, useSavedTargetTime);
      }
      menuDirty = false;
      webServer.resetNetworkAndStartAp();
      enterReady();
      break;

    default:
      break;
  }
}

// Cycles the shutter travel mode and rearms the measurement engine.
void cycleMeasureMode() {
  measureMode = nextMeasurementMode(measureMode);
  engine.cancel();
  engine.setMode(measureMode);
  Serial.printf("[Main] Measurement direction: %s\n", measurementModeKey(measureMode));
  enterReady();
}

// Synchronizes the app state with the measurement engine state.
void handleEngineState() {
  if (engine.isCapturing()) {
    setAppState(AppState::MEASURING);
    return;
  }

  if (engine.hasNewResult()) processNewResult();
}

// Processes a newly finished capture exactly once and prepares the result screen and API data.
void processNewResult() {
  // The API keeps raw timestamps; derived exposure values and measurement hints are handled by the WebUI.
  engine.calculateResults(targetFraction);

  webServer.setLastResult(engine.getResult(), targetFraction, measureMode);

  noteUserActivity();
  Serial.printf("[Main] Result: avg 1/%d s  (%+.2f EV), Mode %s\n",
                engine.getSummary().avgFraction,
                engine.getSummary().avgDeviationStops,
                measurementModeKey(measureMode));

  // Copy the finished result before marking it handled so display and API state stay stable.
  displayedResult = engine.getResult();
  displayedSummary = engine.getSummary();
  displayedMode = measureMode;
  resultPage = 1;
  engine.markResultHandled();

  if (resultDisplayMode == "none") {
    enterReady();
    return;
  }

  setAppState(AppState::RESULTS);
  const unsigned long durationMs = resultDisplayDurationMs(resultDisplayMode);
  resultStartedMs = millis();
  resultDurationMs = durationMs;
  displayDirty = true;
}

// Applies stored settings to UI state, target selection, sensors, and the engine.
void applyRuntimeSettings(bool applySelection, bool useSavedTargetTime) {
  const RuntimeSettings& cfg = webServer.getSettings();

  // Apply settings in separated domains so future changes remain localized.
  applyUiSettings(cfg);
  if (applySelection) applyTargetSettings(cfg, useSavedTargetTime);
  applySensorSettings(cfg);

  engine.setMode(measureMode);
  Serial.printf("[Settings] mode=%s max=1/%d default=1/%d series=%s sensitivity=%s resultDisplay=%s\n",
                measurementModeKey(cfg.defaultMode), DEVICE_MAX_TARGET_TIME, cfg.defaultTargetTime,
                targetSeriesKey(cfg.targetSeries), cfg.sensorSensitivity.c_str(), cfg.resultDisplayMode.c_str());

  displayDirty = true;
}

// Copies display-related settings into runtime variables.
void applyUiSettings(const RuntimeSettings& cfg) {
  resultDisplayMode = cfg.resultDisplayMode;
  oledSleepMinutes = cfg.oledSleepMinutes;
}

// Selects the active target-time series while keeping the current target index stable.
void applyTargetSettings(const RuntimeSettings& cfg, bool useSavedTargetTime) {
  measureMode = cfg.defaultMode;
  targetSeries = cfg.targetSeries;

  if (useSavedTargetTime) {
    targetIndex = targetIndexForTime(cfg.defaultTargetTime, targetSeries);
  } else {
    const int maxIndex = maxTargetIndex(targetSeries);
    if (targetIndex < 0) targetIndex = 0;
    if (targetIndex > maxIndex) targetIndex = maxIndex;
  }

  targetFraction = targetTimeAt(targetIndex, targetSeries);
}

// Applies the configured ADC thresholds.
void applySensorSettings(const RuntimeSettings& cfg) {
  sensorManager.setSensorThresholds(cfg.sensorOnThreshold(), cfg.sensorOffThreshold());
}


// Changes the user-visible app state and schedules a redraw when it changes.
void setAppState(AppState next) {
  if (appState == next) return;
  appState = next;
  displayDirty = true;
}

// Returns true only for device errors that should block measurement capture before a new start attempt.
bool hasBlockingDeviceError() {
  const DeviceError err = currentDeviceError();
  return err != DeviceError::None && err != DeviceError::DisplayInitFailed;
}


// Sets a device error and makes sure no capture continues when an error is active.
void setDeviceError(DeviceError error, DeviceSubsystem subsystem) {
  webServer.setDeviceError(error, subsystem);
  if (error != DeviceError::None) {
    lastOledDeviceError = error;
    enqueueOledNotice("DEVICE ERROR", deviceErrorText(error));
    engine.cancel();
    setAppState(AppState::READY);
    resultStartedMs = 0;
    resultDurationMs = 0;
  }
  displayDirty = true;
}

// Clears a device error globally or only for a specific subsystem.
void clearDeviceError(DeviceSubsystem subsystem) {
  const bool hadError = hasDeviceError();
  webServer.clearDeviceError(subsystem);

  if (hadError || hasDeviceError()) displayDirty = true;
}

// Returns whether any device error is currently reported through the status API.
bool hasDeviceError() {
  return currentDeviceError() != DeviceError::None;
}

// Returns the current device error from the web/status owner.
DeviceError currentDeviceError() {
  return webServer.getDeviceError();
}

// Returns the current network diagnostic hint from the WiFi manager.
NetworkHint currentNetworkHint() {
  return webServer.getNetworkHint();
}

// Queues short OLED notices whenever device or network diagnostics change.
void monitorOledDiagnostics() {
  const DeviceError dev = currentDeviceError();
  if (dev != lastOledDeviceError) {
    lastOledDeviceError = dev;
    if (dev != DeviceError::None) enqueueOledNotice("DEVICE ERROR", deviceErrorText(dev));
  }

  const NetworkHint net = currentNetworkHint();
  if (net != lastOledNetworkHint) {
    lastOledNetworkHint = net;
    if (net != NetworkHint::None) enqueueOledNotice("NETWORK", networkHintText(net));
  }
}

// Returns the current flash-contact state without touching measurement edge tracking.
bool isFlashContactClosed() {
  return sensorManager.isDiagnosticFlashActive(sensorManager.readDiagnosticFlashRaw());
}

// Keeps the OLED status icon live while the flash contact is held closed.
void monitorFlashContactIndicator() {
  const bool closed = isFlashContactClosed();
  if (closed == oledFlashContactClosed) return;
  oledFlashContactClosed = closed;
  if (appState == AppState::READY) displayDirty = true;
}

// Adds a short diagnostic message to the OLED notice queue.
void enqueueOledNotice(const char* title, const char* message) {
  if (!message || !message[0]) return;

  if (oledNoticeCount >= OLED_NOTICE_QUEUE_SIZE) {
    oledNoticeHead = (oledNoticeHead + 1) % OLED_NOTICE_QUEUE_SIZE;
    oledNoticeCount--;
  }

  const uint8_t idx = (oledNoticeHead + oledNoticeCount) % OLED_NOTICE_QUEUE_SIZE;
  strncpy(oledNoticeQueue[idx].title, title && title[0] ? title : "NOTICE", sizeof(oledNoticeQueue[idx].title) - 1);
  oledNoticeQueue[idx].title[sizeof(oledNoticeQueue[idx].title) - 1] = '\0';
  strncpy(oledNoticeQueue[idx].message, message, sizeof(oledNoticeQueue[idx].message) - 1);
  oledNoticeQueue[idx].message[sizeof(oledNoticeQueue[idx].message) - 1] = '\0';
  oledNoticeCount++;

  if (oledNoticeDurationMs == 0) startNextOledNotice();
}

// Starts the next queued OLED notice, waking the panel if necessary.
void startNextOledNotice() {
  if (oledNoticeCount == 0) {
    oledNoticeStartedMs = 0;
    oledNoticeDurationMs = 0;
    activeOledNotice.title[0] = '\0';
    activeOledNotice.message[0] = '\0';
    displayDirty = true;
    return;
  }

  activeOledNotice = oledNoticeQueue[oledNoticeHead];
  oledNoticeHead = (oledNoticeHead + 1) % OLED_NOTICE_QUEUE_SIZE;
  oledNoticeCount--;
  oledNoticeStartedMs = millis();
  oledNoticeDurationMs = OLED_NOTICE_MS;
  lastUserActivity = oledNoticeStartedMs;
  if (displayAvailable && oledSleeping) {
    displayManager.wake();
    oledSleeping = false;
  }
  displayDirty = true;
}

// Returns whether a transient OLED diagnostic notice is currently active.
bool isOledNoticeActive() {
  return oledNoticeDurationMs != 0 && (millis() - oledNoticeStartedMs) < oledNoticeDurationMs;
}

// Advances the OLED notice queue after the current message has expired.
void updateOledNoticeTimer() {
  if (oledNoticeDurationMs == 0) return;
  if (isOledNoticeActive()) return;
  startNextOledNotice();
}

// Returns the app to ready mode and tries to arm the capture engine.
bool enterReady() {
  resultStartedMs = 0;
  resultDurationMs = 0;
  resultPage = 1;
  setAppState(AppState::READY);

  if (hasBlockingDeviceError()) {
    engine.cancel();
    displayDirty = true;
    return false;
  }

  return startMeasurementFromCurrentSettings();
}

// Starts listening with the current target and measurement mode.
bool startMeasurementFromCurrentSettings(bool noteActivity) {
  if (noteActivity) noteUserActivity();
  lastReadyArmAttempt = millis();
  if (!engine.startListening(measureMode)) {
    displayDirty = true;
    return false;
  }
  displayDirty = true;
  return true;
}

// Retries arming while ready if the previous attempt found active inputs.
void maintainReadyCapture() {
  if (appState != AppState::READY || hasBlockingDeviceError()) return;
  if (engine.isArmed() || engine.isCapturing() || engine.hasNewResult()) return;
  if ((millis() - lastReadyArmAttempt) < READY_ARM_RETRY_MS) return;
  startMeasurementFromCurrentSettings(false);
}

// Leaves the result screen and returns to ready mode.
void closeResultsAndReady() {
  enterReady();
}

// Closes the result screen when the selected display timeout has elapsed.
void updateResultsTimeout() {
  if (appState != AppState::RESULTS || resultDurationMs == 0) return;
  if ((millis() - resultStartedMs) >= resultDurationMs) closeResultsAndReady();
}

// Marks the display dirty when WiFi state changes need to be reflected.
void handleWifiEvents() {
  const WifiEvent ev = webServer.consumeWifiEvent();
  if (ev != WifiEvent::None) displayDirty = true;
}
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

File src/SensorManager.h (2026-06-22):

/*
 * Reads the five phototransistors and the flash contact, tracks edges, and exposes live diagnostics.
 */

#pragma once
#include <Arduino.h>
#include "Config.h"
#include "MeasurementTypes.h"

// Hardware-facing capture notes:
// - Phototransistors pull ADC pins downward when light reaches the sensor.
// - The flash contact is active LOW through the configured pull-up input.
class SensorManager {
public:
  // Assigns the five sensor pins and initializes the flash input state.
  SensorManager() : _sensorOnThreshold(SENSOR_ON_THRESHOLD_MEDIUM), _sensorOffThreshold(SENSOR_OFF_THRESHOLD_MEDIUM) {
    const uint8_t pins[] = { PIN_SENSOR_0, PIN_SENSOR_1, PIN_SENSOR_2, PIN_SENSOR_3, PIN_SENSOR_4 };
    for (int i = 0; i < SENSOR_COUNT; i++) {
      _sensors[i].id = i;
      _sensors[i].pin = pins[i];
    }
    _flash.reset();
  }

  // Configures ADC resolution, sensor pins, attenuation, and flash input pull-up.
  void begin() {
    analogReadResolution(12);
    for (int i = 0; i < SENSOR_COUNT; i++) {
      pinMode(_sensors[i].pin, INPUT);
      analogSetPinAttenuation(_sensors[i].pin, ADC_11db);
      _sensors[i].rawValue = 4095;
    }
    pinMode(_flash.pin, INPUT_PULLUP);
    Serial.println(F("[Sensor] Inputs initialized. Dark idle raw is expected near 4095."));
  }

  // Stores absolute ADC hysteresis thresholds for light detection.
  void setSensorThresholds(int onThreshold, int offThreshold) {
    _sensorOnThreshold = constrain(onThreshold, 0, 4095);
    _sensorOffThreshold = constrain(offThreshold, 0, 4095);
    if (_sensorOffThreshold <= _sensorOnThreshold) {
      _sensorOffThreshold = min(4095, _sensorOnThreshold + 100);
    }
    Serial.printf("[Sensor] ADC thresholds: on<=%d off>=%d\n", _sensorOnThreshold, _sensorOffThreshold);
  }

  // Scans unfinished sensors and the flash input once; each sampled ADC channel receives its own timestamp.
  bool update() {
    bool changed = false;
    for (int i = 0; i < SENSOR_COUNT; i++) changed |= updateSensor(_sensors[i]);
    changed |= updateFlashInput(esp_timer_get_time());
    return changed;
  }

  // Updates the flash input using the current timer value.
  bool updateFlashInput() {
    return updateFlashInput(esp_timer_get_time());
  }

  // Updates flash contact state and records the first trigger edge.
  bool updateFlashInput(int64_t timestampUs) {
    _flash.triggeredThisUpdate = false;

    const int val = digitalRead(_flash.pin);
    const bool wasActive = _flash.isActive;
    const bool activeNow = isFlashActive(val);

    _flash.rawValue = val;
    _flash.isActive = activeNow;

    if (!wasActive && activeNow) {
      _flash.triggeredThisUpdate = true;
      if (!_flash.detected) {
        _flash.detected = true;
        _flash.triggerTimestamp = timestampUs;
      }
    }
    return (activeNow != wasActive) || _flash.triggeredThisUpdate;
  }

  // Clears all per-measurement tracking flags for sensors and flash.
  void resetTracking() {
    for (int i = 0; i < SENSOR_COUNT; i++) _sensors[i].resetMeasurement();
    _flash.resetMeasurement();
  }

  // Returns a sensor reading by clamped index.
  SensorReading& getSensor(int idx) {
    if (idx < 0) idx = 0;
    if (idx >= SENSOR_COUNT) idx = SENSOR_COUNT - 1;
    return _sensors[idx];
  }

  // Returns a const sensor reading by clamped index.
  const SensorReading& getSensor(int idx) const {
    if (idx < 0) idx = 0;
    if (idx >= SENSOR_COUNT) idx = SENSOR_COUNT - 1;
    return _sensors[idx];
  }

  // Returns the full sensor reading array.
  const SensorReading* getSensors() const { return _sensors; }
  // Returns the mutable flash reading.
  FlashReading& getFlash() { return _flash; }
  // Returns the flash reading.
  const FlashReading& getFlash() const { return _flash; }

  // Reads a phototransistor for diagnostics without touching measurement edge tracking.
  int readDiagnosticSensorRaw(int idx) const {
    if (idx < 0) idx = 0;
    if (idx >= SENSOR_COUNT) idx = SENSOR_COUNT - 1;
    return readFastSensor(_sensors[idx].pin);
  }

  // Computes whether a diagnostic ADC sample would currently count as active.
  bool isDiagnosticSensorActive(int idx, int raw) const {
    if (idx < 0) idx = 0;
    if (idx >= SENSOR_COUNT) idx = SENSOR_COUNT - 1;
    return raw <= _sensorOnThreshold;
  }

  // Reads the flash contact for diagnostics without touching trigger tracking.
  int readDiagnosticFlashRaw() const { return digitalRead(_flash.pin); }

  // Computes whether a diagnostic flash-contact sample is active.
  bool isDiagnosticFlashActive(int raw) const { return isFlashActive(raw); }

  // Returns the current absolute ADC thresholds for diagnostics.
  int sensorOnThreshold() const { return _sensorOnThreshold; }
  int sensorOffThreshold() const { return _sensorOffThreshold; }


  // Returns true if any sensor is currently active.
  bool isAnySensorActive() const {
    for (int i = 0; i < SENSOR_COUNT; i++) if (_sensors[i].isActive) return true;
    return false;
  }

  // Returns true once every activated sensor is inactive again.
  bool wereAllActivatedSensorsClosed() const {
    for (int i = 0; i < SENSOR_COUNT; i++) if (_sensors[i].wasActivated && _sensors[i].isActive) return false;
    return true;
  }

  // Counts sensors that have opened at least once in the current measurement.
  int countActivated() const {
    int count = 0;
    for (int i = 0; i < SENSOR_COUNT; i++) if (_sensors[i].wasActivated) count++;
    return count;
  }

  // Closes still-active sensors synthetically when a timeout ends the measurement.
  void forceCloseActiveSensors(int64_t timestampUs) {
    for (int i = 0; i < SENSOR_COUNT; i++) {
      SensorReading& s = _sensors[i];
      if (s.wasActivated && s.isActive && s.closeTimestamp == 0) {
        s.isActive = false;
        s.closeTimestamp = timestampUs;
        s.lastEdgeTimestamp = timestampUs;
      }
    }
  }
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

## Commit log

2026-06-20 api cleanup
    [OpenCurtainLab - Bambu A1 mini.3mf, OpenCurtainLab - Battery Door.step, OpenCurtainLab - Battery Door.stl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]
2026-06-22 3d files updated
    [OpenCurtainLab - Battery Door.step, OpenCurtainLab - Battery Door.stl, OpenCurtainLab - Button Frame.step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]
2026-06-24 first hardware test
    [OpenCurtainLab - Bambu A1 mini.3mf, OpenCurtainLab - Case Base.stl]
2026-06-24 battery meter fixes
2026-06-25 documentation fix
    [OpenCurtainLab - Bambu A1 mini.3mf, OpenCurtainLab - Battery Door.step, OpenCurtainLab - Battery Door.stl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]
2026-06-26 small ux fixes
    [Praktica_MTL5_2026-06-25_2232.csv]
2026-06-29 measurement hints are only in the webui
    [OpenCurtainLab - Bambu A1 mini.3mf, Praktica_MTL5_2026-06-25_2232.csv]
